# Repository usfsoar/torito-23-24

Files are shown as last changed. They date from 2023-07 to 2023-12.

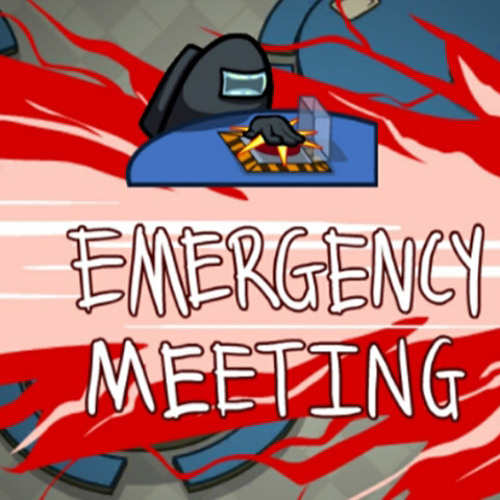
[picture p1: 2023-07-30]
Electronics/GUITest/Emergency.jpg

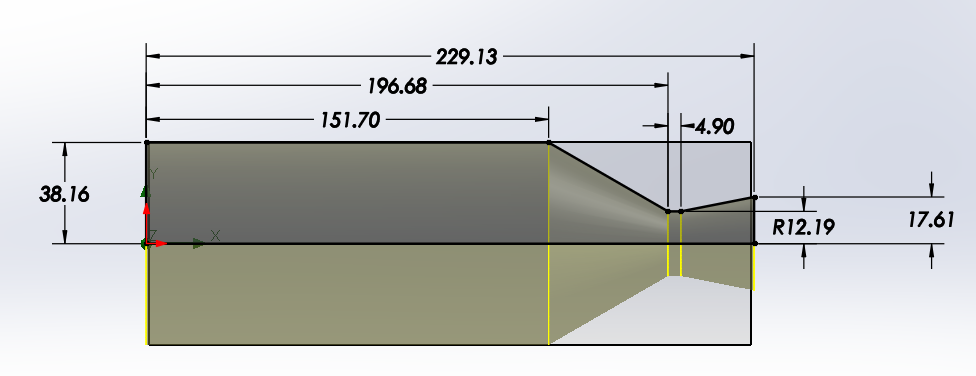
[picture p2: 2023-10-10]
Propulsion & Chemical/100lbf Contour.png

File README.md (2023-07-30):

# README

The following is the README for the Torito project of the USF SOAR club.

### Solenoid Test

This is a folder for the solenoid test over the summer to test if the solenoid valves would allow water to flow through them and what would be needed to allow the solenoids to be used optimally for the torito project.

### GUI Test

GUI was tested in Spring of 2023 to create a GUI and test what the interface would look like if run on a raspberry pi to read sensors and display them.

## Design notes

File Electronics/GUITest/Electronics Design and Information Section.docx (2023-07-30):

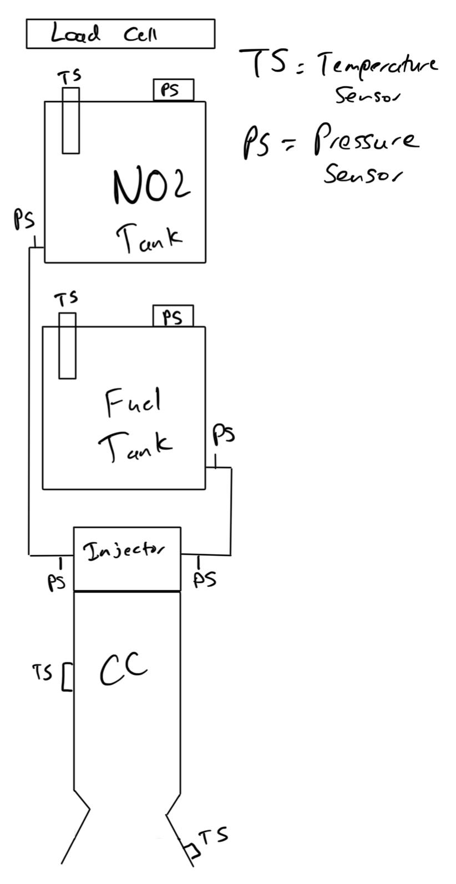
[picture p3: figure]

The way that the sensors will be setup is that they will be interfacing with a raspberry pi zero w. Since the raspberry pi does not have analog to digital pins. This will be counteracted with an analog to digital converter, the MCP3008 chip on Figure 2. This chip is able to input up to 8 different analog to digital pins allowing for more sensors if needed. The way that the design is setup is so that there will be 6 pressure sensors. The temperature sensors, thermocouples, will be able to be read from a raspberry pi plate, the MCC 134, and the plate will sit on top of the raspberry pi. The plate is not featured on Figure 2 because it could not be located in the EasyEDA Library. The plate is able to intake up to 4 thermocouples, 8 wires total and if needed multiple plates can be stacked on top of each other for more input. All the sensor's desired locations are featured in Figure 1. There will be 6 pressure sensors, one on each tank, two at each tanks’ outlet, and the final two at each of the injector inlets. The pressure sensors will be pressure transducers with wire leads and a 3 wire connection. The temperature sensors, thermocouple, will have locations of the two tanks, one on the face of the combustion chamber on the outside, and the last one on the outside of the nozzle. The tank thermocouples can consist of thermocouple probes to read the temperature of each tank. The load cell will be connected to an amplifier as shown in figure 2, and record the force generated by the rocket. The voltage will either have 2 sources, one from the raspberry pi and the other from a 9V battery.

Figure 1: Sensors Location

Another solution to this is to have one larger battery of greater voltage and regulate it using a regulator to distribute power of different voltages to both the raspberry pi and the pressure sensors.

The code for the raspberry pi is a combination of included libraries found on the internet as well as original code to make it work together with a python program to showcase all of the sensor data in a gui format. The gui is updated in half a second intervals so that the most accurate readings from the sensors that are being fed into the raspberry pi from the various sources. The interval of reading sensors can be modified according to the desired interval of time in seconds. The method of communication for the raspberry pi is through ssh, where a computer can connect to the raspberry and it will have the code already on it for reading the sensors and a gui will be displayed to the connected computer, all the connected computer will need to do is run the python script. The data will be displayed on the gui as well be saved in a csv file, a comma separated list, and will be easily accessible through an excel program.

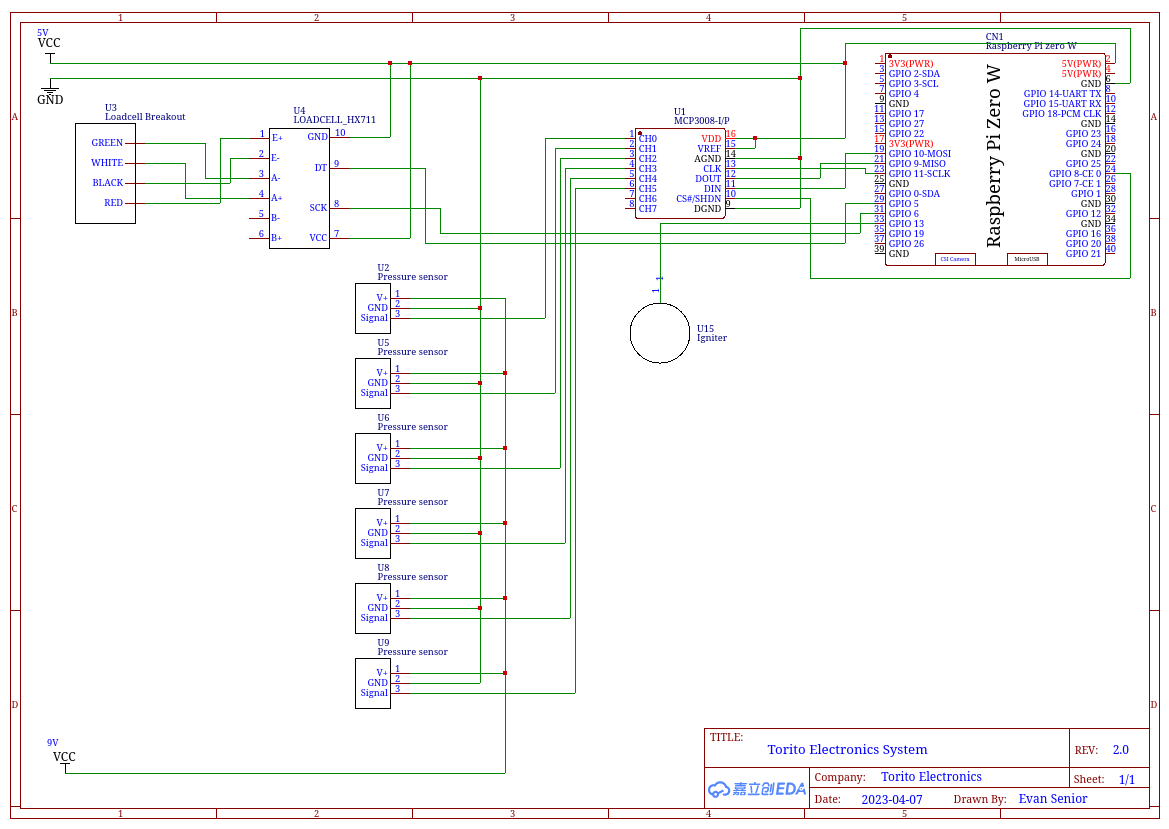
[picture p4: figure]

Figure 2: Schematic of the Raspberry Pi Zero W Circuit

The location of all the electrical components will be located on the test stand itself. The raspberry pi will be securely connected in front of the load cell where it will not be damaged if the nozzle and combustion chamber become loose. It will also be in a secure location as to if something does go wrong in a bad case, the data from the raspberry pi will be collected and stored not just on the raspberry pi but also on the host machine connected to the raspberry pi every refresh interval, half a second. The code also saves the data file in a csv format every interval so if the sd card used for the pi is not damaged but the pi itself is damaged the data is still retrievable.

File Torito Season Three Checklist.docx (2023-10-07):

Season Three October 7, 2023 – October 15, 2023

Week 1: October 7, 2023 – October 14, 2023

Structures

- Inventory of Test Stand (!!!)
- Plasma Cutter (!)
- More Disassembly (!!!)

Chemical/Propulsion

- Post Table (!!!!)
- More Research (why fuel rich?) (!!!)
- Mess around configs (!!!)
- Kendal and James need help! (!!!!)

Electrical

- Work on GitHub organization for Torito (!)

Week 2: October 15, 2023 – October 21, 2023

Structures

- Start Building Frame (!)

Chemical/ Propulsion

- Mess around configs (!!!)
- Multiple Plate Config Sims (!!!)
- Find Pressures for Injector Inlet (!!)
- Plot Data

Electrical

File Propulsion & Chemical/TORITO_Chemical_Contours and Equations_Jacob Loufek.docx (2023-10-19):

# Water Flow Test

## 1-1 Engine Contours


| (mm)
Combustion Chamber (Diameter) | 38.16
Combustion Chamber (Length) | 151.70
Nozzle Throat (Length) | 4.90
Nozzle Throat (Radius) | 12.19
Nozzle Exit (Radius) | 17.61

## 2-1 Parameters

### 2.1.1 Characteristic Length L*

L* = Characteristic Length (m)

Vc = Volume of the Combustion Chamber ( m^3 )

At = Area of the Throat (m^2 )

This value, L *, is generally used for determining the combustion chamber volume rather than the stay time. Compare charts and compare stay time to literature data. The L* is found using past experiments/experience using a similar engine/Propellant combination. [1]

## 2-1 Design Equations

### 2.1.1 Goal

The Ultimate Goa

Given the cross sectional area of the nozzle throat

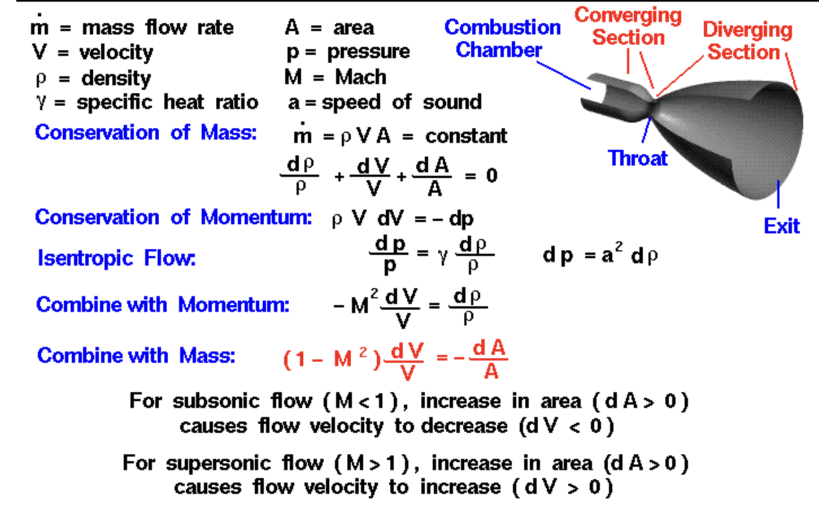
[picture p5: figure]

https://www.grc.nasa.gov/www/k-12/rocket/nozzle.html

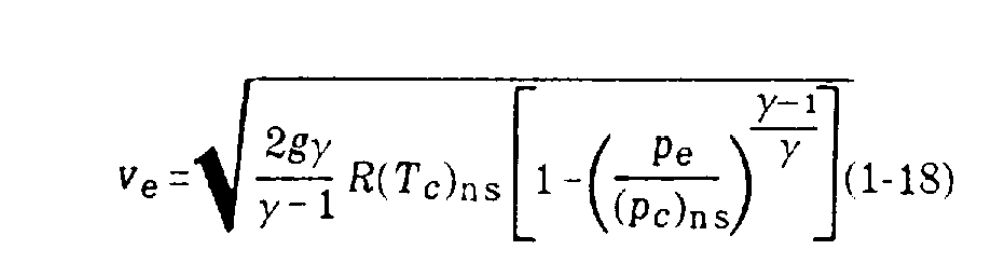
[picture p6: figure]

https://ntrs.nasa.gov/api/citations/19710019929/downloads/19710019929.pdf

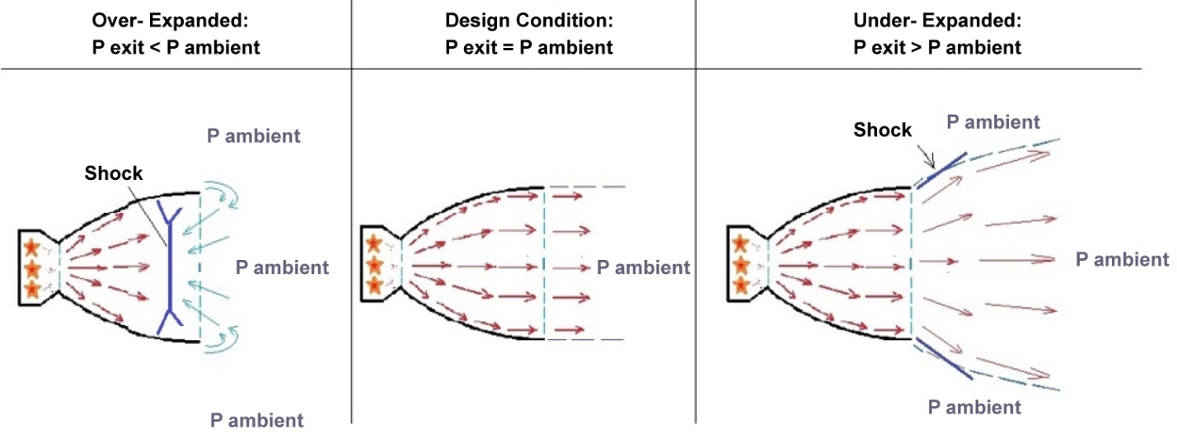
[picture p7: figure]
Development of an Aerospike Nozzle for a High Performance Green Hybrid Propulsion (Hpghp) System for Small Satellites

https://www.engineeringtoolbox.com/standard-atmosphere-d_604.html

# Udemy Course Summary

## Introduction: The Ideal Rocket

- Isentropic
  - Both adiabatic and reversible
  - The work transfers of the system are frictionless
  - No transfer of heat or matter
- 11 Assumptions
  - The chemical reaction products is homogeneous
  - All species of working fluid are gaseous. Any condensed phases (liquid or solid) add a negligible amount to the total mass
  - Working substance obeys perfect gas law
  - Adiabatic: No heat transfer across the rocket walls
  - No appreciable friction + all boundary layer effects are negelected
  - No shock waves or dicotinuities in nozzle flow
  - Propellant flow is stead and constant
    - Expansion of working fluid is uniform and steady (without vibration0
    - Transient effects (starup and shutdown) are of very short duration and may be neglected
  - All exhaust gases leaving the rocket have an axially directed velocity
  - Gas velocity, pressure, temperature, and density are all uniform across ay section normal to the nozzle axis
  - Chemical Equilibrium is established within the rocket chamber + gas composition does not change in the nozzle (frozen flow)
  - Stored propellants are at room temperature

## Mass Flow Rate in Isentropic Flow

## Deriving the Flow Equation

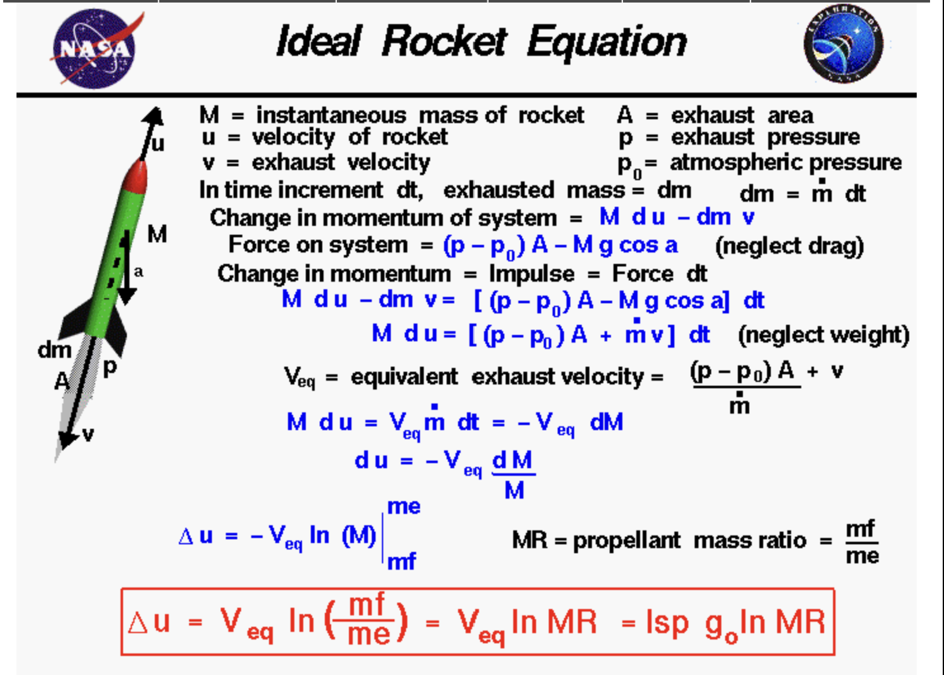
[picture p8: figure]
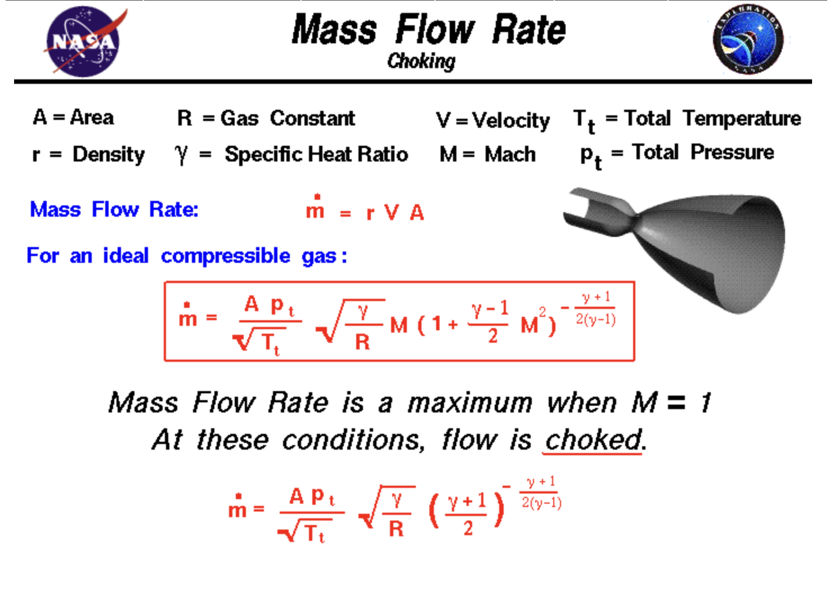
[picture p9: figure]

# Bibliography

[1] | C. S. Austin Sennott, "How to Design Pressure Vessels, Propellant Tanks," Half Cat Rocketry Technical Resources, Austin Sennott.
[2] | D. K. H. a. D. H. H. liang, "Design of Liquid Propellant Rocket Engines," NASA, 1967. [Online]. Available: https://ntrs.nasa.gov/api/citations/19710019929/downloads/19710019929.pdf.
[3] | "Understanding Performance Fittings – Straight and AN Threads vs. Tapered Thread," SpeedNews, [Online]. Available: https://nasaspeed.news/tech/engine/understanding-performance-fittings-straight-and-an-threads-vs-tapered-thread/.

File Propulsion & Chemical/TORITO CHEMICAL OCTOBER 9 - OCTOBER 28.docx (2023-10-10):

# TORITO CHEMICAL

## OCTOBER 9 – OCTOBER 28

What is needed to complete this objective | Objective | What will be done with this objective?
Understanding of MATLAB code for the injector | Determine inlet specifications to the injector plate including Temperature, pressure, mass flow rate of fluids
Mass flow rate through combustion chamber might give us idea of total mass flow rate in the liquid state | Analyze O/F ratios [T_0 / m] Ratio in NASA CEA

Resources

1. List_of_Resources_Torito_Propulsion_1.xlsx (https://usfedu.sharepoint.com/:x:/r/teams/SocietyofAeronauticsandRocketryGRP/Shared%20Documents/Torito/General%20Resources/List_of_Resources_Torito_Propulsion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)

2. Sizing Orifices of an Injector (https://www.shawnvictor.net/injector-orifice-sizing.html)

3. NASA CEA (https://cearun.grc.nasa.gov/)

4. Example Design Calculations for Orifice (https://risacher.org/rocket/example.html)

5. USF SOAR GITHUB (https://github.com/usfsoar)

# Sizing Orifices of an Injector

## 1.0. Variables

- Need to know
  - What are your propellants
  - Upstream pressure of the propellants
  - Overall thrust you are trying to achieve
- Useful Tool
  - NASA CEA (https://cearun.grc.nasa.gov/) - helps with the intensive thermodynamics and chemical mathematics

## 2.0 Example Google Sheet

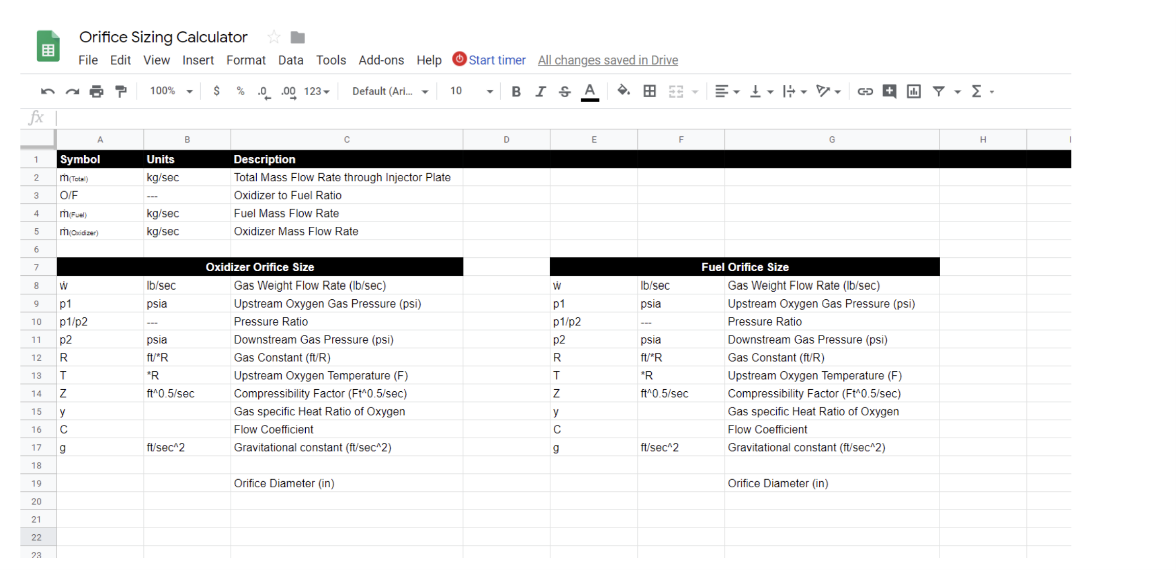
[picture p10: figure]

## 3.0 Using NASA CEA

## 3.1 Determine total mass flow rate

## 3.2 Input combustion chamber pressure (Units: PSIA)

- Determine tank holding pressure aka "run tank"
- In an ideal case
  - Pressures loses in our feed system are negligible ie. they compromise ~ 1% loss
- Downstream pressure (combustion chamber) needs to be half of the pressure located on the input side of the injector plate
  - This ensures that flow does not go backwards (choked flow)
  - Personal thought: If we know the combustion chamber pressure through RPA, then we can multiply by 2 and determine? Keep in mind volatility of the propellant though when making this decision

## 3.3 Choose your fuel and oxidizer

## 3.4 Submit input and Perform CEA Analysis

## 3.5 Consider melting point of chosen material

- Check that NASA CEA results for engine temperature well below melting point of material
- Use a factor of safety of 1.5 or greater
- Equation: (Melting Point of material / 1.5) and then round down.
  - Output: Desired Maximum temperature of our engine

## 3.6 Oxidizer to Fuel Ratio

- Stoichiometric Ratio
  - Highest point of temperature
  - Just enough oxidizer to mix with all the fuel needed
- Oxidizer in Excess
  - Temperature decreases
- The more wasted propellant => propellant has the potential to add more energy to the system through combustion but it just exhausted out the nozzle => less efficient engine
- Higher temperature => more efficiency
- Note:
  - We are more constrained to melting point of material rather than ability to have combustion at the stoichiometric ratio

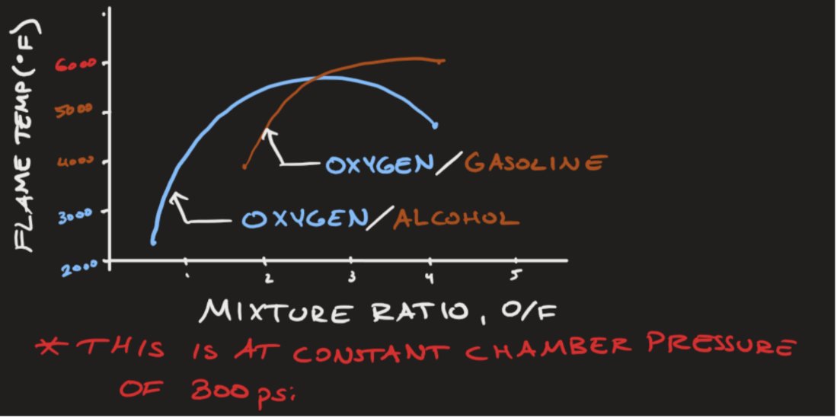
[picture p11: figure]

## 3.7

- Run NASA CEA data to see (i) O/F Ratios and (ii) Chamber Temperatures
- Look for O/F Ratios to see how close you can get to the Maximum Determined Chamber Temperature
  - Remember, this must be the lower bound of the melting point of the material

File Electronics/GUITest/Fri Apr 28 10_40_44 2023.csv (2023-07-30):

Time Since Launch | P Sensor1 | P Sensor2 | n-1 Sensor | Temp 1 | Temp 2 | Temp 3 | Temp 4
0s | 1 | 2 | ... | 0 | 1 | 3 | 4
0.5s | 14 | 13 | ... | 10 | 101 | 3 | 8
1.0s | 16 | 22 | ... | 20 | 201 | 12 | 15
1.5s | 24 | 38 | ... | 30 | 301 | 14 | 15
2.0s | 40 | 52 | ... | 40 | 401 | 21 | 17
2.5s | 55 | 56 | ... | 50 | 501 | 21 | 18
3.0s | 73 | 58 | ... | 60 | 601 | 24 | 23
3.5s | 75 | 63 | ... | 70 | 701 | 28 | 23
4.0s | 89 | 65 | ... | 80 | 801 | 32 | 32
4.5s | 108 | 72 | ... | 90 | 901 | 41 | 35
5.0s | 123 | 91 | ... | 100 | 1001 | 45 | 44
5.5s | 138 | 111 | ... | 110 | 1101 | 49 | 52
6.0s | 153 | 119 | ... | 120 | 1201 | 58 | 54
6.5s | 160 | 137 | ... | 130 | 1301 | 59 | 54
7.0s | 179 | 144 | ... | 140 | 1401 | 63 | 61
7.5s | 192 | 156 | ... | 150 | 1501 | 64 | 66
8.0s | 203 | 157 | ... | 160 | 1601 | 71 | 71
8.5s | 206 | 163 | ... | 170 | 1701 | 77 | 71
9.0s | 219 | 183 | ... | 180 | 1801 | 84 | 79
9.5s | 221 | 200 | ... | 190 | 1901 | 88 | 81
10.0s | 233 | 215 | ... | 200 | 2001 | 93 | 82
10.5s | 245 | 216 | ... | 210 | 2101 | 96 | 85
11.0s | 255 | 223 | ... | 220 | 2201 | 96 | 92
11.5s | 263 | 225 | ... | 230 | 2301 | 97 | 99
12.0s | 282 | 236 | ... | 240 | 2401 | 98 | 107

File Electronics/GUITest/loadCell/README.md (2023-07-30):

# HX711 for Raspbery Py
----
Quick code credited to [underdoeg](https://github.com/underdoeg/)'s [Gist HX711.py](https://gist.github.com/underdoeg/98a38b54f889fce2b237).
I've only made a few modifications on the way the captured bits are processed and to support Two's Complement, which it didn't.

Update: 25/02/2021
----
For the past years I haven't been able to maintain this library because I had too much workload. Now I'm back and I've been working on a few fixes and modifications to simplify this library, and I might be commiting the branch by mid-March. I will also publish it to PIP.

Instructions
------------
Check example.py to see how it works.

Installation
------------
1. Clone or download and unpack this repository
2. In the repository directory, run
```
sudo pip install setuptools
sudo python setup.py install
```
Had problems installing and setting up load cell on personal Linux machine, might not be the case on rasberry pi. Should be able to run commands without sudo.

Using a 2-channel HX711 module
------------------------------
Channel A has selectable gain of 128 or 64.  Using set_gain(128) or set_gain(64)
selects channel A with the specified gain.

Using set_gain(32) selects channel B at the fixed gain of 32.  The tare_B(),
get_value_B() and get_weight_B() functions do this for you.

This info was obtained from an HX711 datasheet located at
https://cdn.sparkfun.com/datasheets/Sensors/ForceFlex/hx711_english.pdf

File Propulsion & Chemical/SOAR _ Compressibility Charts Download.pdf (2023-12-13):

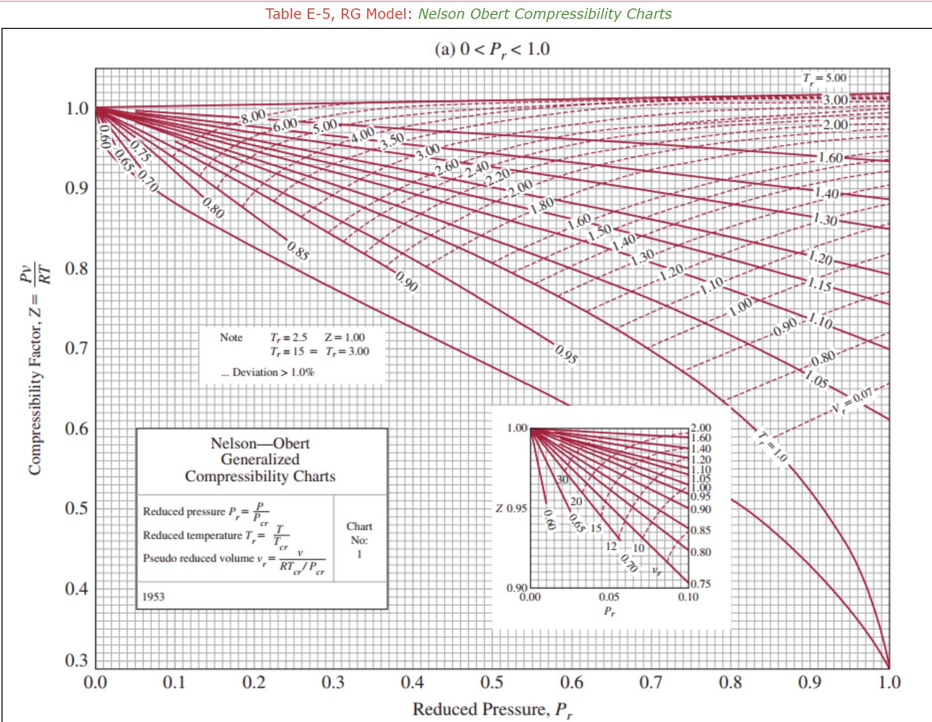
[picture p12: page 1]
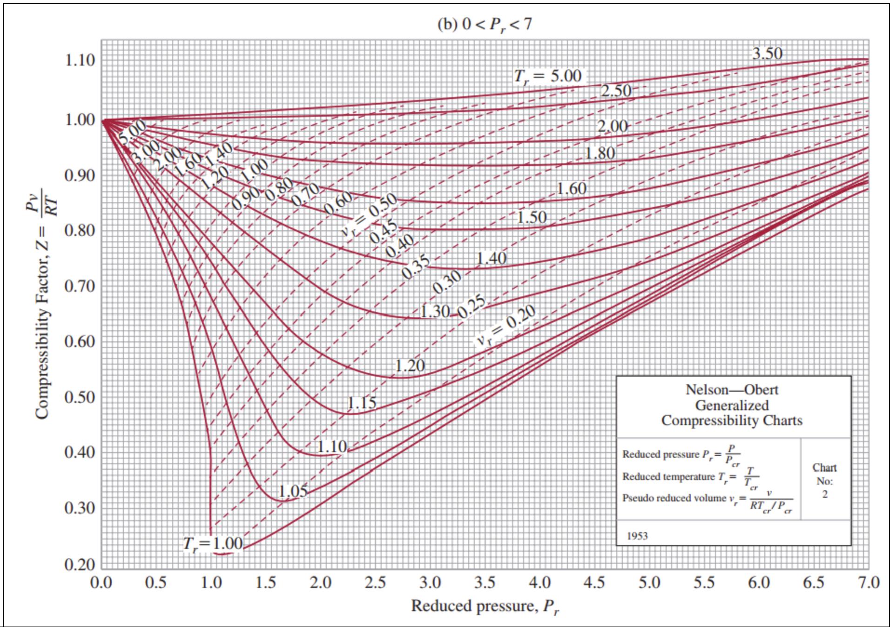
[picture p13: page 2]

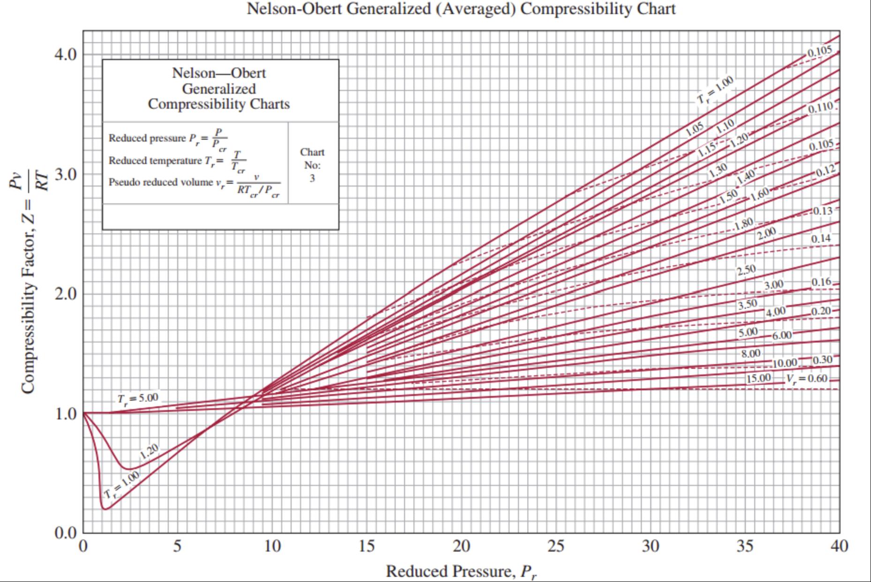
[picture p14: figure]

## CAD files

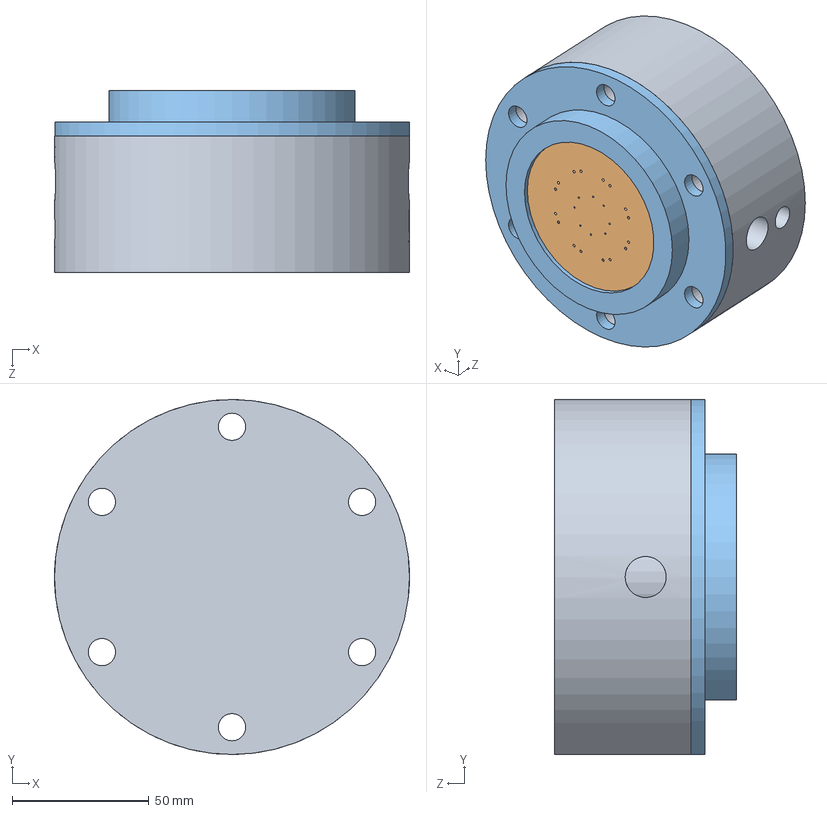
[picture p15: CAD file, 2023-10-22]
Propulsion & Chemical/Juans Scuffed CAD/Config 2 Casing Proposal.SLDASM
130.0 x 130.0 x 66.5 mm
Injector Holder
Injector_Plate_MR_4.5_Configuration_2
Injector Flow Guide

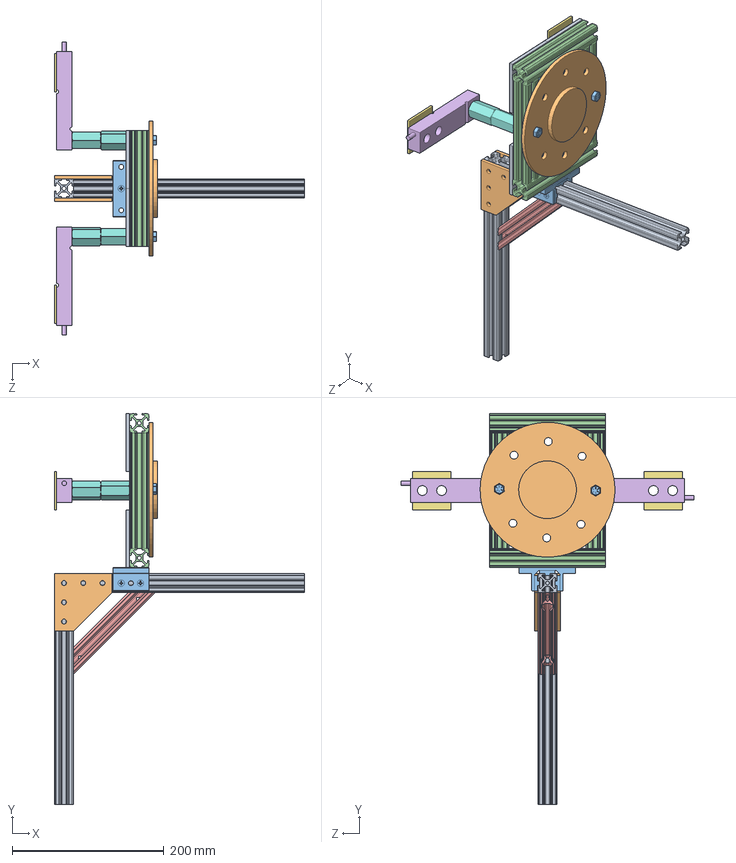
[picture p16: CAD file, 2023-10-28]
Structures design CAD/TestMount_v2.SLDASM
330.2 x 515.8 x 387.0 mm
47065T1_T-Slotted Framing x 2
47065T267_T-Slotted Framing (1) x 2
47065T959_T-Slotted Framing (1)
47065T563_T-Slotted Framing x 4
47065T186_T-Slotted Framing
500 kg Load Cell x 2
Load Cell Shim 8896K117 x 2
92499A721_18-8 SS MALE-FEM HEX THRD ADAPTER x 4
3136N157_T-Slotted Framing (2) x 4
injectorV1
91268A196_High-Strength Grade 8 Steel Hex Head Screw x 2

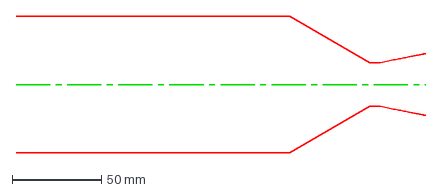
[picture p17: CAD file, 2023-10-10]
Propulsion & Chemical/100lbf chamber contour.dxf
229.1 x 76.2 mm

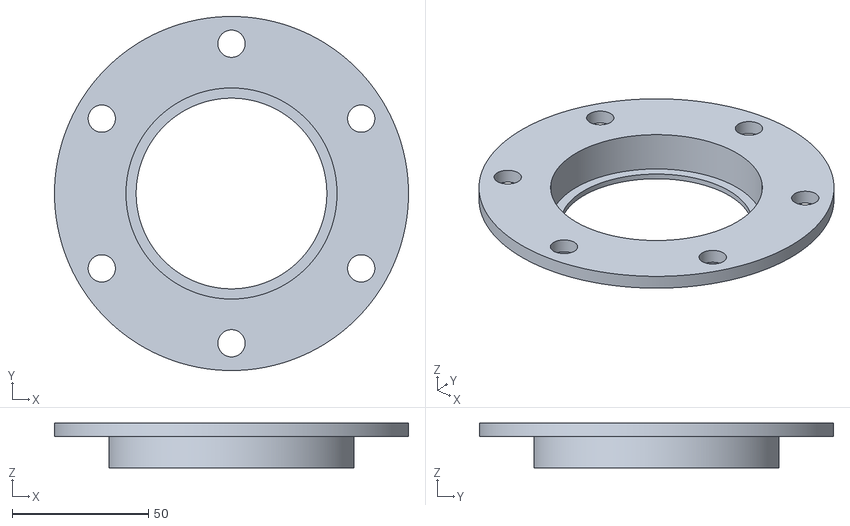
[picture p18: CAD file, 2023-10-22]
Propulsion & Chemical/Juans Scuffed CAD/Injector Holder STL.STL
130.0 x 130.0 x 16.5

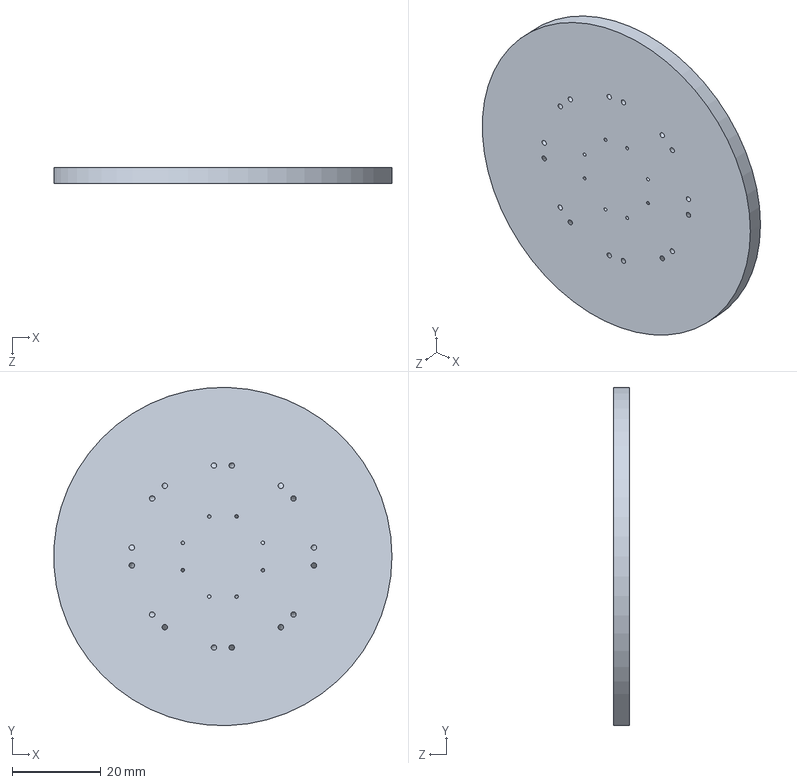
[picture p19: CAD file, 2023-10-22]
Propulsion & Chemical/Juans Scuffed CAD/Injector_Plate_MR_4.5_Configuration_2.SLDPRT
76.1 x 76.2 x 3.69 mm

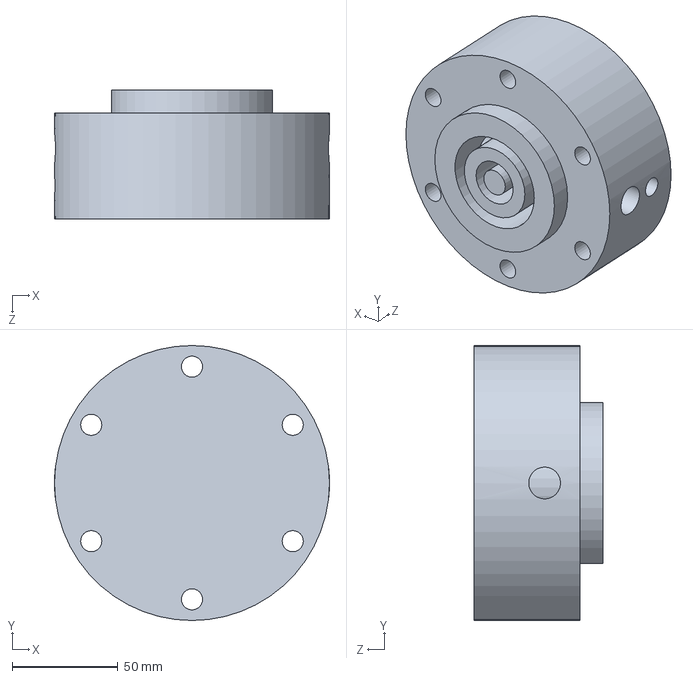
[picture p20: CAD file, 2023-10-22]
Propulsion & Chemical/Juans Scuffed CAD/Injector Flow Guide.SLDPRT
130.0 x 130.0 x 60.8 mm

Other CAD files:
Propulsion & Chemical/Juans Scuffed CAD/Injector Holder.SLDPRT
Propulsion & Chemical/Juans Scuffed CAD/Injector Flow Guide.STL

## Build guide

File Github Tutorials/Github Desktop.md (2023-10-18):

# Github Desktop

To get started with this tutorial, you will want to download the Github desktop application from this [link](https://desktop.github.com/)

Then when you load the application and set it up, it is going to ask you for a repository that you would like to copy. You will need to get the link from the green code button at the top of the repository and copy the link. The alternative is you can open the repository in the dekstop app by pressing open in Github Desktop when you press the green code button.

From there it should have clone the repository to your local machine. Then when you make changes to files and documents you can go to that repository and upload them there. Once they are in the local repository, open the Github desktop app and it will show the changes made in the local file system. You then add a summary and description, optional, and press the commit button in the bottom left of the application. This will then upload the changes you made to any files on the web version of github.

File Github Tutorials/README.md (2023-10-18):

# Github Tutorials

Please follow this [video](https://www.youtube.com/watch?v=iv8rSLsi1xo&list=PLWzABT4GTysfyFTM2mAiKjuKCykMu_FTr&index=1&pp=gAQBiAQB) for the basic understanding of github before reading further.

There are a few main components of github itself, as stated in the video github desktop is probably the eaisest way to use github. The reason I recommend github desktop is it intuitive and easy to navigate, while offering everything github has to offer. You can also access many features the github website also has to offer without having to login to the website.

### Terminology

The following are some keywords to remember when using github:

- Push - This will save any changes you made to a file to the github website.
- Pull - This will apply any changes that were made on the desktop that are not in your local files.
- Commit - Commit is sharing what changes you made before you push to the github website.
- Stage - Often time you will not see stage, but if you make changes you have to "stage" the changes before you can commit and push the modified file
- Fetch - This will also apply any changes that were made on the desktop that were not in your local files
- Sync - The most important one. After you commit your changes sync will sync with the github webstie files. This means if you made changes and someone else made changes and saved to the website before you, it will make sure your part is appended on.
- Merge Conflict - The second part to sync. This will review the changes made on the website and your local files. It will ask if you want to append to the already editied document that was saved on the github website. This will only show up as stated before if you try to modify a document that was recently updated and the most recent version was not saved on your local machine.

### Supported File Types

The following are supported file types that their commit changes can be viewed inside of the commit log, as well as be uploaded to github:

- SVG
- LOG
- TXT
- CSV
- md
- STL (Can be rendered and previewed)
- (Any Coding Language)

The following files types are not supported when showing their commit changes, but can still be uploaded to github:

- SolidWorks Files
- PNG
- GIF
- JPEG
- DOCX/Microsoft Files
- PDF
- ZIP
- MP4

## Other Tutorials

Once you understand this tutorial you can find other tutorials in this folder/directory.

- [Github Desktop Tutorial](https://github.com/usfsoar/torito-23-24/blob/main/Github%20Tutorials/Github%20Desktop.md#github-desktop)

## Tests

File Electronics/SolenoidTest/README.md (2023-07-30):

# Solenoid Test

The following folder is the code and write up for setting up the raspberry pi to test a solenoid. The raspeberry pi is connected to a relay and then the relay is connected to GPIO pin 23.

For further instructions on setting up the rasperrby pi please see the Electronics Guide to Setup. There are also video examples of the code working as well as wet and dry tests of the solenoid properly performing given the correct setup and supplies.

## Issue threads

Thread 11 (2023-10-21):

Test Load Cell

Kurogue, 2023-10-21:

Kurogue, 2023-10-28:
- [ ] Test Voltage Differential
- [ ] Test to see if value comes out of PI after connecting load cell
- [ ] Calibrate Load Cell with PI connected (try to get appropriate lbs out of it)

Kurogue, 2023-11-04:
Testing done with the load cell when not connected to the amplifier. 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 Once the amplifier has been purchased the load cell can be properly tested.

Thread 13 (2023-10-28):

Prepare data and information for 3 different materials

Face69, 2023-10-28:
Current Specs for hypothetical Situation
(i)	Injector
a.	Plate diameter = 0.0762 m
b.	Orifice Diameter [Fuel] = 0.00805996 m
c.	Orifice Diameter [Oxidizer] = 0.0012304 m
d.	Number of Fuel Orifices = 8
e.	Number of Oxidizer Orifices = 16

(ii)	Thrust = 800 lbf
(iii)	Chamber Pressure = 400 ps

(iv)	Material Choice
a.	Graphite
b.	Alumnium
c.	316 Stainless Steel

Closed 2024-02-21.

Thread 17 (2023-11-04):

Test Sensors

Kurogue, 2023-11-04:

Kurogue, 2023-11-04:
Test sensors from the old test design using voltmeter to see if the connections are still good.

Closed 2023-11-17.

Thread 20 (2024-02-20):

FEA Simulation on the Injector Design

stephanielue8088, 2024-02-20:
### Description

-  Produce an FEA simulation for the existing injector system to asses pressure tolerances.
- The injector system includes the top plate + injector plate

### What to do with this simulation
[ ]  Prepare a document of analyses for the simulation
[ ]  What information do we care about
[ ]  How do you see ourselves using this information to make certain decisions

Closed 2024-04-01.

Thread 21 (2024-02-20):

Solenoid Valve Python Script Review

stephanielue8088, 2024-02-20:
### Objective

- Be able to have a general understanding of the existing python script that Evan used to program the solenoid valve
- Be able to develop an understanding of the [Electronics Guide to Set Up](https://usfedu.sharepoint.com/:w:/r/teams/SocietyofAeronauticsandRocketryGRP/Shared%20Documents/Torito/Torito_Electronics/Electronics%20Guide%20to%20Setup.docx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)

### What should be done with this information
- Document certain concepts or topics that you believe persons should be familiar with so they can have a better understanding. This can range from how solenoid valves work, to python libraries, to raspberry pi etc.
     -  This is rather broad but the idea is to help the team fill in any gaps that could help us develop a more holistic view and can guide us towards our next steps in sensor testing

- Share your findings and understandings at an alignment meeting, or meet with one of the leads.

### The following files can be seen in order

- [ ] [Solenoid Test Read Me](https://github.com/usfsoar/torito-23-24/blob/main/Electronics/SolenoidTest/README.md)

- [ ] [Solenoid Valve Program](https://github.com/usfsoar/torito-23-24/blob/main/Electronics/SolenoidTest/SolenoidGUI.py)

- [ ] [Electronics System Schematic](https://usfedu.sharepoint.com/teams/SocietyofAeronauticsandRocketryGRP/Shared%20Documents/Forms/AllItems.aspx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)

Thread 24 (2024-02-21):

Official Email to Professors

stephanielue8088, 2024-02-21:
### Description
  :e-mail: Send out an official email to Dr. Vasel, Dr. Box and Dr. Rodrigo inviting them to our presentation
  :e-mail: CC Enrique, Jacob and Juan (Pres, VP, Project Lead)

### Details

- 📆 Friday March 22nd
- ⏲  4:30 - 5:30 PM
- 🏠  ENC3408

Closed 2024-02-28.

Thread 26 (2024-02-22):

Nozzle Design Equation in MATLAB Live Editor

stephanielue8088, 2024-02-22:
### What are we curious about
[ ] How does MATLAB Live Editor work and what could benefits for us?
[ ] The motive behind looking into MATLAB Live editor is to see if it can be used to help persons develop a general understanding of the general nozzle design equations

### Resources

### Possible Approach
1. Search for a reliable website/book that displays the nozzle design equations
2. Focus on equations that evaluate throat area, thrust, exit velocity (consider everything else given such as temperature, pressure etc)
3. Develop calculators in MATLAB Live Editor to provide the outputs listed above
4. Learn the basics of LaTEX syntax and use it to transform the MATLAB Live Editor page to appear like a document

### If the above is too easy xD (do this no balls)
1. Look into "sliders" on MATLAB Live Editor.
2. Try to develop sliders so that the results of the equations change with any variable
3. Develop another visual way to display these changes (you brought the example of a weather map from programming concepts)

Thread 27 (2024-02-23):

Assign to Leaders: Look into developing "knock-off" version of Solid Works PDM

stephanielue8088, 2024-02-23:
**LOL I asked ChatGPT to help us come up with a temporary solution for managing SS parts.**

> [!TIP]
>**File Naming Convention:**
>Establish a clear and consistent naming convention for your SolidWorks part files. Include relevant information such as project name, part name, version number, and date. This helps team members quickly identify the latest version of a file.

>[!TIP]
>**Version Control in File Names:**
>Incorporate version numbers or revision letters directly into the file names. For example, "PartName_V1", "PartName_V2", or "PartName_RevA".

>[!TIP]
>**Folder Structure:**
>Create a well-organized folder structure to store your SolidWorks part files. Group files by project, assembly, or specific categories to make navigation easier. Include separate folders for current versions, previous versions, and archived files.

>[!TIP]
>Document Control Sheet:
>Maintain a document control sheet or spreadsheet to track the history of revisions for each part file. Include information such as version number, date of revision, changes made, and author.

>[!TIP]
>Revision Control:
>Implement a clear revision control process. Define criteria for when a new version or revision should be created, such as significant design changes or updates based on feedback.

>[!TIP]
>**Check-In/Check-Out System:**
>Establish a check-in/check-out system similar to SolidWorks PDM, where team members must check out a file before making changes and check it back in once modifications are complete. This prevents conflicts and ensures that everyone is working on the latest version.

>[!TIP]
>**Collaboration Tools:**
>Utilize collaboration tools and software to facilitate communication and file sharing among team members. Platforms like Microsoft Teams, Slack, or project management tools often have integrations with SolidWorks or support file sharing capabilities.

>[!TIP]
>**Regular Backups:**
>Implement a regular backup system to prevent data loss. Schedule automated backups of your SolidWorks part files and ensure that backups are stored securely, either onsite or in the cloud.

By implementing these strategies, your team can effectively manage SolidWorks part files, track versions, and collaborate more efficiently, even without using SolidWorks PDM.

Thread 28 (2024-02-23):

Navier-Stokes Estimation of Exit Velocity Injector Plate

stephanielue8088, 2024-02-23:
### 🎏 Objective
[ ] Estimate the exit velocity of water at room temperature through the injector plate assuming that we are given the boundary pressures, inlet temperature, inlet velocity,

### ⛰️ Guidelines
[ ]  Document assumptions
[ ]  Document units being used/desired
[ ]  Document units of the values provided and the appropriate conversion to desired units
[ ] Revisit the CFD and review the inputs. Review [Numerical Basis of CAD-Embedded CFD](https://www.solidworks.com/sw/docs/flow_basis_of_cad_embedded_cfd_whitepaper.pdf) to assess any changes we can make

### ✅ How Do I Submit My Work?
Put all your work in this link (lol put the link for the template)

 ### 🔗 Possible Resources
[Injector Plate Dimensions](https://usfedu.sharepoint.com/:w:/t/SocietyofAeronauticsandRocketryGRP/EUFEyHTyhbVPvvntsML1L-8BJWPHKKy6Co-uea3snkfAig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)
[Numerical Basis of CAD-Embedded CFD](https://www.solidworks.com/sw/docs/flow_basis_of_cad_embedded_cfd_whitepaper.pdf)
[Navier Stokes Equation Derivations and Applications](https://www.researchgate.net/publication/334579546_Optimizing_Beverage_Pasteurization_Using_Computational_Fluid_Dynamics): **This Link also touches on CFD**

### YouTube Resources
[Chemical Engineering Fluid Mechanics P1](https://www.youtube.com/watch?v=xLQNqwPUuN4)
[Chemical Engineering Fluid Mechanics P2](https://www.youtube.com/watch?v=pVLCmT5lkw4)
[Chemical Engineering Fluid Mechanics P3](https://www.youtube.com/watch?v=UCWYMwx8kjg)
[Chemical Engineering Fluid Mechanics](https://www.youtube.com/watch?v=mtoHgKdXLJk&t=784s)
[Derivation of Navier Stokes](https://www.youtube.com/watch?v=NjoMoH51UZc)

### Injector Sources
[Screenshots of the Injector SW](https://usfedu.sharepoint.com/:w:/t/SocietyofAeronauticsandRocketryGRP/EUFEyHTyhbVPvvntsML1L-8B7U181RvgdtwvpZfE-UszEQ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)
[Injector MATLAB Code](https://usfedu.sharepoint.com/:u:/t/SocietyofAeronauticsandRocketryGRP/EZL5teWS-E1Njt0GUUinpIIB_3ZX5gDFXxaEXFmD6Mx1eA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)

stephanielue8088, 2024-02-23:
@kgary1 @stephanielue8088 create  a "template" for @emilyh1100 for upload final deliverable
Due: Friday March 1st,
Check-in: Wed/Thursday
Buffer: Tuesday March 5th

Closed 2024-03-03.

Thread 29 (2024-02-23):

Engine Design : Three [3]

stephanielue8088, 2024-02-23:
### 🎏 Objective
[ ] We want to prepare 3 engine designs by using NASA CEA and RPA

### 🚀 What do the engine design not include?

- Material type
- Ablative
- Do not worry about the diameter of the chamber at the entrance

### 🚵‍♀️  Process
1. Use NASA CEA to obtain O/F versus Temperature graphs for the chamber. We have done this before. For reference, see [this link]
(https://usfedu.sharepoint.com/:w:/t/SocietyofAeronauticsandRocketryGRP/ER_gVfd0j9lJj7vr4aOE_sEBXf1dhCWeJ4l9PvSao0hlrA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). Here, use the Chamber Pressure specified in Table 1.0 Chamber Pressure – Thrust Combinations.
2. **Open RPA**
3. **Open Engine Definition.**
    ➡️ Enter the value for Chamber Pressure
    ➡️ Enter the value for "nominal thrust" into RPA according to the thrust specified in Table 1.0 Chamber Pressure – Thrust
          Combinations.
6. **Open Propellent Specifications**
     ➡️Add liquid nitrous oxide and liquid 95% ethanol
8. **Open Nozzle Flow Model**
     ➡️ For Nozzle Exit Condition, set this to 1.01325 atm
10. **Hit Run**
11. **Open Engine Design** >> Chamber Geometry >> Design Parameters**
     ➡️ Record the Characteristic Length L*
13.  **Engine Design >> Chamber Geometry >> Size and Geometry**
      ➡️Record Dc (chamber diameter)

### ❓ What Do I do with this information?
Save the file an upload here for analysis later.

### ❓ How do I know whether or not I should make another simulation
1. In NASA CEA, check if Maximum temperature after O/F Temperature analysis is no greater than 2900K
2. In RPA, check that  L* = 66 inches = 1676 mm ~ 1-2 m

>[!TIP]
> See if you can simulate the rocket in
[[OLD] Base 11 Preliminary Request for Static Test Fire.pdf](https://github.com/usfsoar/torito-23-24/files/14382347/OLD.Base.11.Preliminary.Request.for.Static.Test.Fire.pdf)
>[Video](https://www.youtube.com/watch?v=b9NcdDhhZio)

stephanielue8088, 2024-02-23:
@stephanielue8088 Create a template for which to put this information on.

stephanielue8088, 2024-03-15:
Please see Engine Designs [here](https://usfedu.sharepoint.com/:f:/r/teams/SocietyofAeronauticsandRocketryGRP/Shared%20Documents/Torito/[Proposal](https://usfedu.sharepoint.com/:f:/r/teams/SocietyofAeronauticsandRocketryGRP/Shared%20Documents/Torito/Proposal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)?csf=1&web=1&e=wwiBaB)

Closed 2024-03-15.

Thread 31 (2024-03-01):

Navier - Stokes Velocity Profile

stephanielue8088, 2024-03-01:
### Description
Develop a velocity profile with respect to radius (such that the reference is the center line of the orifice which is basically a cylindrical tube) in MATLAB

### Guidance 🤝
Step 1: Review and identify your dependent, independent and constant variables
Step 2: Convert your variables into METRIC.
Step 3: Use MATLAB and the picture reference below to develop the Velocity Profile against radius,r
Step 4: Save your file as navier_stokes_yourname_VX where X is the version of your work

For example
``` matlab
navier_stokes_steph_v1
```

Step 5: Upload your work to [Navier_Stokes_Injector Folder](https://usfedu.sharepoint.com/:f:/t/SocietyofAeronauticsandRocketryGRP/Eg9D8gYMeO5Aq7yg7ytsXJYBLXY_s3mmWstqqgP51FwQKg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)

### Useful Information 💯

Fluid: Water at room temperature
Chamber Pressure=100 psi
Injector PressureDrop: 20% of the chamber pressure
Injector Orifice Length of the Oxidizer =  0.00299185 m
Mass Flow of the Oxidizer = 0.0953266 kg/s
Diameter of the Oxidizer Orifice =  0.000997284 m

### Assumptions 🤔

- Laminar Flow
- Constant viscosity and density
- Steady State
- Horizontal flow (no gravitational effects)
- Constant Temperature

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

stephanielue8088, 2024-03-01:
@kgary1 Here is what Faith and Juan will be working on. This is due next Tuesday March 5

Face69, 2024-03-01:
I fried myself lel

stephanielue8088, 2024-03-03:
Both codes have been uploaded
Code to be revisited to sort our pressure drop challenge

Closed 2024-03-03.

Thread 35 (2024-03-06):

Rocket Propulsion Analysis

stephanielue8088, 2024-03-06:
**For a**

✅ Chamber Pressure of 150 psi
✅  Nominal Thrust of 118 lbf
✅ And for a range of O/F ratios [ Fuel Rich, Stoichiometric (the parabola of the graph), Oxidizer Rich], use Rocket
      Propulsion Analysis

1. Record the L*. Ideally it should be close enough to 60 inches = 1524 mm . Error +/- 1 inches. Record in inches
2. Record Dc (Chamber Diameter) in mm. Convert this to inches.
3. For the Injector, Nozzle Inlet, Nozzle Throat and Nozzle Exit, record the following

    ☑  Pressure
    ☑  Temperature
    ☑  Viscosity
    ☑  Velocity
    ☑  Gamma

Please see below for reference:

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

stephanielue8088, 2024-03-06:
Hey @Gabbytb1 , here is the data is used to generate the graphs [Excel File](https://usfedu.sharepoint.com/:x:/r/teams/SocietyofAeronauticsandRocketryGRP/Shared%20Documents/Torito/Torito_Chemical/Basic%20Engine%20Designs%20for%20March%2022%20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)

Closed 2024-04-01.

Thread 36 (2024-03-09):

Derive water flow thing that you got today (Venturi Meter Equation)

stephanielue8088, 2024-03-09:
Deliverables
[] Create a single document that outlines how we resolved exit velocities discrepancies. Put info in [here](https://usfedu.sharepoint.com/:w:/r/teams/SocietyofAeronauticsandRocketryGRP/Shared%20Documents/Torito/Torito_Propulsion/Minion%20Shenanigans/Exit%20Velocities%20Ver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)

Notes
- From Flow sim data, PG Velocity [Num] are the max velocities
-

Closed 2024-03-12.

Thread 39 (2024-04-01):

MODEL SPT25 Pressure Transducer Summary Guide Tool

stephanielue8088, 2024-04-01:
🛠**Develop a tool that will allow persons to quickly do the following**

[ ] Determine signs of certain hazards such as fluid hammers and surges, for example
[ ] Steps that must be taken to avoid certain hazards
[ ] Installation procedure and guidelines

💯  **ACTION**

Please upload you work to [Sensor Documentation Folder](https://usfedu.sharepoint.com/:u:/r/teams/SocietyofAeronauticsandRocketryGRP/SitePages/[Home](https://usfedu.sharepoint.com/:u:/r/teams/SocietyofAeronauticsandRocketryGRP/SitePages/Home.aspx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).aspx?csf=1&web=1&e=uiFAEv)

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

Closed 2024-04-06.

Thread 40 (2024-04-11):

PID List of Materials

stephanielue8088, 2024-04-11:
Complete list of materials from PID V5 2020.
Complete in this excel sheet: [here](https://usfedu.sharepoint.com/:x:/t/SocietyofAeronauticsandRocketryGRP/Ea6EfRMOT5FKjD4KY42W88IButVmp5i-0ivsGOSHlvlCHA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)
You can use [this key as a guide](https://usfedu.sharepoint.com/:b:/r/teams/SocietyofAeronauticsandRocketryGRP/Shared%20Documents/Torito/Torito_Electronics/Sensor%20Documentation/Relevant%20Torito%20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)

Closed 2024-04-15.

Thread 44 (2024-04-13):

Ask Dr. Baksh to review CAD Drawings for Xometry

stephanielue8088, 2024-04-13:
[ ] Present CAD Drawings to Dr. Box. Here are the current versions as of 4-13-2024: [CAD Drawings](https://usfedu.sharepoint.com/:f:/t/SocietyofAeronauticsandRocketryGRP/EgK6AzqcgIBCmLkNbazrSnEBj9aA7Cq02T7PpU7AShyinw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).  Show [Xometry requirements](https://www.xometry.com/resources/design-guides/technical-drawing-best-practices/)
[ ] Ask Dr. Box what information should we pay attention to when reviewing the ASTM specifications. How do we choose ASTM Specifications such as A582 and A240
[ ] Ask Dr. Box  about Section 6 : Ensure views align with the projection view.
[ ] Ask Dr. Box Ask about the following sections in the 2 images below
[] Ask Dr. Box about 'surface finishes and tolerances for the orifice holes'
[ ] Email Xometry :
- What ASTM standards are offered. We would like to manufacture an item out of Stainless Steel 316
- Do we need to specify all dimensions in the drawings or just the threads, tapped holes and tolerances

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

stephanielue8088, 2024-04-14:
Recommendations from alumnus Brandon
[] Add more detail to the orifice holes
[] And for the o-ring grooves, those might have specs you need to meet for a proper seal. Like surface finish and dimensional tolerances, that aren’t on this drawing

Closed 2024-04-20.

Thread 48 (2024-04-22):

Bill of Materials

stephanielue8088, 2024-04-22:
### Bill of Materials

[ ] Create a table of the Pros and Cons for Raspberry Pi and allow the team to vote by 4/22/24
[ ] Re-Do the drawings for Xometry
[ ] Have B.O.M for Plumbing

Don't forget to look into these resources

- [ ] Water Flow Testing
- [ ] Notes from Jay in the forum

Closed 2024-05-09.

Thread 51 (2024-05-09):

Labels for Plumbing Parts

stephanielue8088, 2024-05-09:
In the [Plumbing Materials Spring 2024 Excel Sheet](https://usfedu.sharepoint.com/:x:/t/SocietyofAeronauticsandRocketryGRP/Ea6EfRMOT5FKjD4KY42W88IButVmp5i-0ivsGOSHlvlCHA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)

1. Click on each link corresponding to each part. You can...

- [ ]  Ignore the rows that are filled with gray
- [ ]  Pay attention to only McMaster links

2. Complete the columns labeled

- [ ] For Use With
- [ ] Material
- [ ] Maximum Pressure
- [ ] Part Number

>[!NOTE]
> The part number can be find in the CAD image

>[!TIP]
> If you cannot find certain information, just put n/a

Closed 2024-05-18.

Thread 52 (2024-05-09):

Assembly and Tightening of JIC and NPT fittings

stephanielue8088, 2024-05-09:

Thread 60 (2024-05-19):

Torque Chart for Parts

stephanielue8088, 2024-05-19:
### Reference https://github.com/usfsoar/torito-23-24/issues/52

For each bolt/not/NPT fitting/JIC fitting, determine the torque required. Include both for dry ( or lightly oiled) and lubricated. This is a simple calculation. The math to do this is in https://github.com/usfsoar/torito-23-24/issues/52.

Note to @stephanielue8088 : Link where the task should be done. Maybe the plumbing excel sheet?

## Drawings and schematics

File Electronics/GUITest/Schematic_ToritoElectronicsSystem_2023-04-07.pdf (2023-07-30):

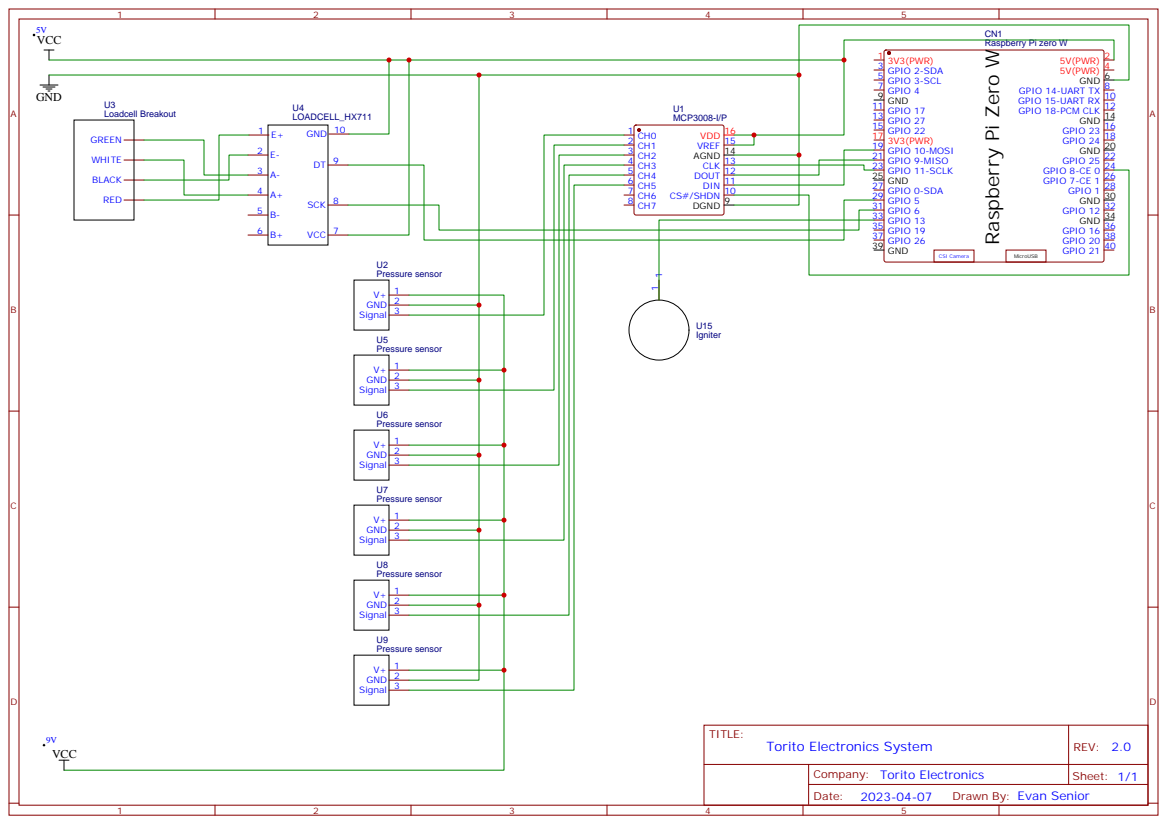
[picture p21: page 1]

Drawn By: Evan Senior

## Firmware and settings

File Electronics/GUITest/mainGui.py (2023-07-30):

from tkinter import *
import time
import sys
from datetime import datetime
import csv
import piplates.THERMOplate as THERMO
import Adafruit_GPIO.SPI as SPI
import Adafruit_MCP3008

print('Reading Sensor values, press Ctrl-C to quit...')

#Main frame for the GUI
root = Tk()

#Lables for the GUI
lab1 = Label(root)
filler = Label(root)
pSensor1 = Label(root)
pSensor2 = Label(root)
pSensor3 = Label(root)
pSensor4 = Label(root)
pSensor5 = Label(root)
pSensor6 = Label(root)
pSensor7 = Label(root)
pSensor8 = Label(root)
filler2 = Label(root)
tSensor1 = Label(root)
tSensor2 = Label(root)
tSensor3 = Label(root)
tSensor4 = Label(root)
loadCell = Label(root)

#Pack the labels onto the GUI
lab1.pack()
filler.pack()
pSensor1.pack() 
pSensor2.pack() 
pSensor3.pack() 
pSensor4.pack() 
pSensor5.pack() 
pSensor6.pack() 
pSensor7.pack() 
pSensor8.pack()
filler2.pack()
tSensor1.pack()
tSensor2.pack()
tSensor3.pack()
tSensor4.pack()
loadCell.pack()

#Variables for stuff
filename = time.ctime() + ".csv"
f = open(filename, "w")
output = csv.writer(f)

#data = ["Time Since Launch", "Tank 1", "Tank 2", "n-1 Sensor", "Last Sensor"] - example
data = ["Time Since Launch", "Sensor1", "Sensor2", "n-1 Sensor", "Last Sensor", "Load Cell"]
output.writerow(data)

#Pressure Sensors\Conversion
# Software SPI configuration:
CLK  = 18
MISO = 23
MOSI = 24
CS   = 25
mcp = Adafruit_MCP3008.MCP3008(clk=CLK, cs=CS, miso=MISO, mosi=MOSI)

# Hardware SPI configuration:
# SPI_PORT   = 0
# SPI_DEVICE = 0
# mcp = Adafruit_MCP3008.MCP3008(spi=SPI.SpiDev(SPI_PORT, SPI_DEVICE))


#Load Cell Configuration
#Please see loadCellExample.py for any confusion or calibration that needs to be done
EMULATE_HX711=False

referenceUnit = 1

if not EMULATE_HX711:
    import RPi.GPIO as GPIO
    from hx711 import HX711
else:
    from emulated_hx711 import HX711

def cleanAndExit():
    print("Cleaning...")

    if not EMULATE_HX711:
        GPIO.cleanup()
        
    print("Bye!")
    sys.exit()

hx = HX711(5, 6)
hx.set_reading_format("MSB", "MSB")
hx.set_reference_unit(113)

# If 2000 grams is 184000 then 1000 grams is 184000 / 2000 = 92.
#The above line is used to calibrate the load cell to make sure you are getting proper weight
hx.set_reference_unit(referenceUnit)
hx.reset()
hx.tare()

#Variables
timeSinceLaunch = 0

#Pressure sensors
values = [0]*8
for i in range(8):
    values[i] = mcp.read_adc(i)

#Thermo Plates Sensors
#Can change the k in the string to c, f, or k to get the repsective temperature scale
THERMO.setSCALE('k')
#Need to define them before function call or it will throw an error
t1 = THERMO.getTEMP(0,1)
t2 = THERMO.getTemp(0,2)
t3 = THERMO.getTemp(0,3)
t4 = THERMO.getTemp(0,4)

#Inital Load Cell Force
val = hx.get_weight(5)
pounds = val * 0.0022
poundsPerForce = pounds * 32.174049 #Ft/s^2
hx.power_down()
hx.power_up()

#Functions for updating the sensors
def updateSensor():
    global timeSinceLaunch
    global t1
    global t2
    global t3
    global t4
    global values
    timeSinceLaunch += 0.5 #Dependent on the refresh rate of the update
    t1 = THERMO.getTEMP(0,1)
    t2 = THERMO.getTemp(0,2)
    t3 = THERMO.getTemp(0,3)
    t4 = THERMO.getTemp(0,4)
    for i in range(8)
        values[i] = mcp.read_adc(i)

    
    val = hx.get_weight(5)

    #For any confusion prease go to loadCellExample.py
    #CONVERT THE VALUE FROM GRAMS TO LBS THEN FROM LBS TO LBS PER FORCE, thanks future me, also integrate this into the mainGui.py you lazy bum
    pounds = val * 0.0022
    poundsPerForce = pounds * 32.174049 #Ft/s^2

    #If only want positive values then set the line above to val = max(0, int(hx.get_weight(5)))
    #Was print(val) which prints out grams only
    # print(poundsPerForce)

    # To get weight from both channels (if you have load cells hooked up 
    # to both channel A and B), do something like this
    #val_A = hx.get_weight_A(5)
    #val_B = hx.get_weight_B(5)
    #print "A: %s  B: %s" % ( val_A, val_B )

    hx.power_down()
    hx.power_up()

def FileWrite():
    f = open(filename, "a")
    output = csv.writer(f)
    data = [str(timeSinceLaunch) + "s", values[1], values[2], "...", t1, t2, t3, t4, poundsPerForce]
    output.writerow(data)
    f.close()

def update():
    lab1['text'] = time.ctime() + " | Time Since Launch: " + str(timeSinceLaunch) + "s"
    filler['text'] = "-"*100
    pSensor1['text'] = "Pressure Sensor 1: " + str(values[0]) + " PSI"
    pSensor2['text'] = "Pressure Sensor 2: " + str(values[1]) + " PSI"
    pSensor3['text'] = "Pressure Sensor 3: " + str(values[2]) + " PSI"
    pSensor4['text'] = "Pressure Sensor 4: " + str(values[3]) + " PSI"
    pSensor5['text'] = "Pressure Sensor 5: " + str(values[4]) + " PSI"
    pSensor6['text'] = "Pressure Sensor 6: " + str(values[5]) + " PSI"
    pSensor7['text'] = "Pressure Sensor 7: " + str(values[6]) + " PSI"
    pSensor8['text'] = "Pressure Sensor 8: " + str(values[7]) + " PSI"
    filler2['text'] = " "*100
    tSensor1['text'] = "Thermo Sensor 1: " + str(t1) + " F"
    tSensor2['text'] = "Thermo Sensor 2: " + str(t2) + " F"
    tSensor3['text'] = "Thermo Sensor 3: " + str(t3) + " F"
    tSensor4['text'] = "Thermo Sensor 4: " + str(t4) + " F"
    loadCell['text'] = "Load Cell: " + str(poundsPerForce) + "lbs/f"
    FileWrite()
    updateSensor()
    root.after(500, update) # run itself again after 500 ms

# run first time for recrsive infinite loop
update()

root.mainloop()

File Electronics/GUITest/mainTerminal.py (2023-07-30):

import time
import os
from datetime import datetime
import csv
import piplates.THERMOplate as THERMO
import Adafruit_GPIO.SPI as SPI
import Adafruit_MCP3008

print('Reading Sensor values, press Ctrl-C to quit...')


#Filing Initalization for reading
filename = time.ctime() + ".csv"
f = open(filename, "w")
output = csv.writer(f)

timeSinceLaunch = 0

#data = ["Time Since Launch", "Tank 1", "Tank 2", "n-1 Sensor", "Last Sensor"] example
data = ["Time Since Launch", "Sensor1", "Sensor2", "n-1 Sensor", "Last Sensor"]
output.writerow(data)


#Pressure Sensors\Conversion
# Software SPI configuration:
CLK  = 18
MISO = 23
MOSI = 24
CS   = 25
mcp = Adafruit_MCP3008.MCP3008(clk=CLK, cs=CS, miso=MISO, mosi=MOSI)

# Hardware SPI configuration:
# SPI_PORT   = 0
# SPI_DEVICE = 0
# mcp = Adafruit_MCP3008.MCP3008(spi=SPI.SpiDev(SPI_PORT, SPI_DEVICE))


#Thermo Plates Code
THERMO.setSCALE('f')
#Need to define them before function call or it will throw an error
t1 = THERMO.getTEMP(0,1)
t2 = THERMO.getTemp(0,2)
t3 = THERMO.getTemp(0,3)
t4 = THERMO.getTemp(0,4)


#Functions go before main loop
def FileWrite():
    data = [str(timeSinceLaunch) + "s", values[1], values[2], "...", t1, t2, t3, t4]
    output.writerow(data)


# Main program loop.
while True:
    # Read all the ADC channel values in a list.
    os.system('clear')
    print('Reading Sensor values, press Ctrl-C to quit...')

    #Getting thermocouples Termperature
    t1 = THERMO.getTEMP(0,1)
    t2 = THERMO.getTemp(0,2)
    t3 = THERMO.getTemp(0,3)
    t4 = THERMO.getTemp(0,4)

    values = [0]*8
    for i in range(8):
        # The read_adc function will get the value of the specified channel (0-7).
        values[i] = mcp.read_adc(i)
    # Print the ADC values.
    #print('Current Time | PSensor {0:>4} | PSensor {1:>4} | PSensor {2:>4} | PSensor {3:>4} | PSensor {4:>4} | PSensor {5:>4} | PSensor {6:>4} | PSensor {7:>4} |'.format(*range(8)), "TSensor 1 | TSensor 2 | TSensor 3 | TSensor 4")
    #print(time.ctime(), '| {0:>4} | {1:>4} | {2:>4} | {3:>4} | {4:>4} | {5:>4} | {6:>4} | {7:>4} |'.format(*values), str(t1) + "F | ", str(t2) + "F | ", str(t3) + "F | ", str(t4) + "F")
    # Pause for half a second.
    print(time.ctime(), "| Current Time: ", datetime.now().strftime("%H:%M:%S"))
    print("-"*60)
    for i in range(len(values)):
        print("Pressure Sensor", i, ":", values[i])
    print("Temp Sensor 1: ", t1, "F")
    print("Temp Sensor 2: ", t2, "F")
    print("Temp Sensor 3: ", t3, "F")
    print("Temp Sensor 4: ", t4, "F")
    f = open(filename, "a")
    output = csv.writer(f)
    FileWrite()
    timeSinceLaunch += 0.5
    f.close()
    time.sleep(0.5)

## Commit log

2023-07-30 Added Solenoid Test Files
2023-07-30 Added GUI Testing, must rename and sort the files
    [Fri Apr 28 10_40_44 2023.csv]
2023-09-22 Organization of Folders
    [Fri Apr 28 10_40_44 2023.csv]
2023-10-13 Update README.md
    Will add more files into how to specifically render the stl files
2023-10-21 I added scuffed cad files
    test
    [Assem1.SLDASM, Injector Holder.SLDPRT, Injector_Plate_MR_4.5_Configuration_2.SLDPRT]
2023-10-22 Finished prototype of casing for second config of injector
    Renamed assembly file too
    [Assem1.SLDASM, Config 2 Casing Proposal.SLDASM, Injector Flow Guide.SLDPRT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]
2023-10-22 Fixed some issues
    [Config 2 Casing Proposal.SLDASM, Injector Holder STL.STL, Injector Holder for 3D Print.STL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]
2023-10-22 Added printable STL for the flow guide file
    [Injector Flow Guide.STL]
2023-10-28 Added Assembly: Engine Mount V2
    [TestMount_v2.SLDASM]
